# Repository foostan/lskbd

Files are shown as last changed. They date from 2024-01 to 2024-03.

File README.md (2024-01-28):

# lskbd

lskbd-low-layout v1 top
lskbd-low-layout v1 front
lskbd-low-layout v1 back

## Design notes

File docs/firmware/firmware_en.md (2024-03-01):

# Firmware

## Flash the firmware
Download the firmware of VIA from below
- [lskbd_rev1_via.uf2](https://github.com/foostan/kbd_firmware/blob/main/keyboards/lskbd/qmk/qmk_firmware/.build/lskbd_rev1_via.uf2)

Connect to the PC while holding down the BOOT button, or while connected to the PC, hold down the BOOT button and press the RESET button.
After that, an RPI-PR2 device will be mounted.

btn

Drop the downloaded uf2 file into the RPI-PR2 device to complete flash.

flash

Once the firmware has been written to one side, follow the same procedure for the other side.

## (Optional) If you build the firmware yourself

Refer to [the QMK _getting started_ guide](https://docs.qmk.fm/#/newbs_getting_started),
and install the necessary software according to your OS
(it takes quite some time to install).

Once the environment is ready,
build the firmware for LSKBD with the following files.
https://github.com/foostan/kbd_firmware/tree/main/keyboards/lskbd/qmk/qmk_firmware

## Change your keymap

Please download json file from bellow and load at VIA
- [lskbd](https://github.com/foostan/kbd_firmware/blob/main/keyboards/lskbd/the-via/lskbd.json)

load_json
loaded_json

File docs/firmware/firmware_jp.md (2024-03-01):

# ファームウェア

## ファームウェアを書き込む

VIA用のファームウェアを下記からダウンロードします
- [lskbd_rev1_via.uf2](https://github.com/foostan/kbd_firmware/blob/main/keyboards/lskbd/qmk/qmk_firmware/.build/lskbd_rev1_via.uf2)

BOOTボタンを押しながらPCに接続するか、PCに接続した状態でBOOTボタンを押しながらリセットボタンを押します。
すると、RPI-PR2デバイスがマウントされます。

btn

ダウンロードしたuf2ファイルをRPI-PR2デバイスにドロップすると書き込みが完了します。

flash

片側にファームウェアの書き込みが完了したら、もう片方も同じ手順で書き込みを行います。

## (オプション) 自分でファームウェアをビルドする場合

[the QMK _getting started_ guide](https://docs.qmk.fm/#/newbs_getting_started) こちらを参照して頂き、ファームウェアを書き込む環境を用意します。

環境ができましたら、下記のファイルを利用して自身でビルドを行ってください。
https://github.com/foostan/kbd_firmware/tree/main/keyboards/crkbd/qmk/qmk_firmware

## Change your keymap

下記からjsonファイルをダウンロードし、VIAでロードしてください。
- [lskbd](https://github.com/foostan/kbd_firmware/blob/main/keyboards/lskbd/the-via/lskbd.json)

load_json
loaded_json

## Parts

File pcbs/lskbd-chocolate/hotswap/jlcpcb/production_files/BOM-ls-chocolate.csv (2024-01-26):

Comment | Designator | Footprint | LCSC
W25Q128JVSIQ | U3,rU3 | SOIC-8_5.23x5.23mm_P1.27mm | C113767
1k | R4,R7,rR4,rR7 | R_0402_1005Metric | C11702
TPD4E05U06DQAR | U2,rU2 | USON-10_2.5x1.0mm_P0.5mm | C138714
NCP1117LPST33T3G | U1,rU1 | SOT-223-3_TabPin2 | C146799
100n | C10,C11,C12,C4,C5,C6,C7,C8,C9,rC10,rC11,rC12,rC4,rC5,rC6,rC7,rC8,rC9 | C_0402_1005Metric | C1525
10u | C1,C2,rC1,rC2 | C_0402_1005Metric | C15525
27p | C15,C16,rC15,rC16 | C_0402_1005Metric | C1557
RP2040 | U4,rU4 | QFN-56-1EP_7x7mm_P0.4mm_EP3.2x3.2mm | C2040
1N4148WT | D1,rD1 | D_SOD-523 | C232841
10k | R3,rR3 | R_0402_1005Metric | C25744
5.1k | R1,R2,rR1,rR2 | R_0402_1005Metric | C25905
ST-0277D00-052-142 | J1,rJ1 | ST-0277D00-052-142 | C2837093
BSMD0603-050-12V | F1,rF1 | Fuse_0603_1608Metric | C2844464
TYPE-C-31-M-13C | J3,rJ3 | TYPE-C-31-M-13C | C2848620
ESD5Z5V0C | ZD1,rZD1 | D_SOD-523 | C2901325
27 | R5,R6,rR5,rR6 | R_0402_1005Metric | C2909343
TS-1088R-02026 | SMDSW1,SMDSW2,rSMDSW1,rSMDSW2 | TS-1088R-02026 | C455280
YS-SK6812MINI-E | LED1,LED10,LED11,LED12,LED13,LED14,LED15,LED16,LED17,LED18,LED19,LED2,LED20,LED21,LED22,LED23,LED24,LED3,LED4,LED5,LED6,LED7,LED8,LED9,rLED1,rLED10,rLED11,rLED12,rLED13,rLED14,rLED15,rLED16,rLED17,rLED18,rLED19,rLED2,rLED20,rLED21,rLED22,rLED23,rLED24,rLED3,rLED4,rLED5,rLED6,rLED7,rLED8,rLED9 | YS-SK6812MINI-E | C5149201
1u | C13,C14,C3,rC13,rC14,rC3 | C_0402_1005Metric | C52923
SW_Push | SW1,SW10,SW11,SW12,SW13,SW14,SW15,SW16,SW17,SW18,SW19,SW2,SW20,SW21,SW22,SW23,SW24,SW3,SW4,SW5,SW6,SW7,SW8,SW9,rSW1,rSW10,rSW11,rSW12,rSW13,rSW14,rSW15,rSW16,rSW17,rSW18,rSW19,rSW2,rSW20,rSW21,rSW22,rSW23,rSW24,rSW3,rSW4,rSW5,rSW6,rSW7,rSW8,rSW9 | keyswitch_choc12_hotswap_1u | C5333465
12MHz 18pF | Y1,rY1 | Crystal_SMD_3225-4Pin_3.2x2.5mm | C91749

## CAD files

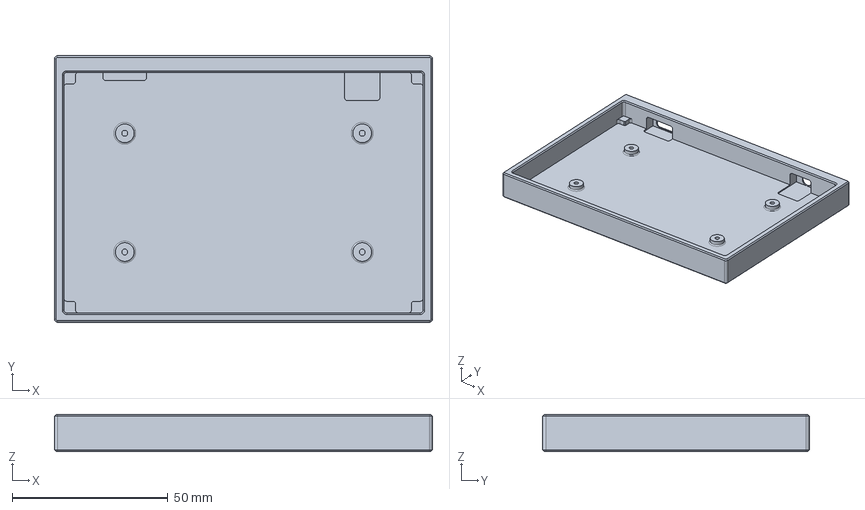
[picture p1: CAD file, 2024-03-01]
cases/lskbd-chocolate/lskbd-chocolate-left.step
121.3 x 85.5 x 11.9 mm

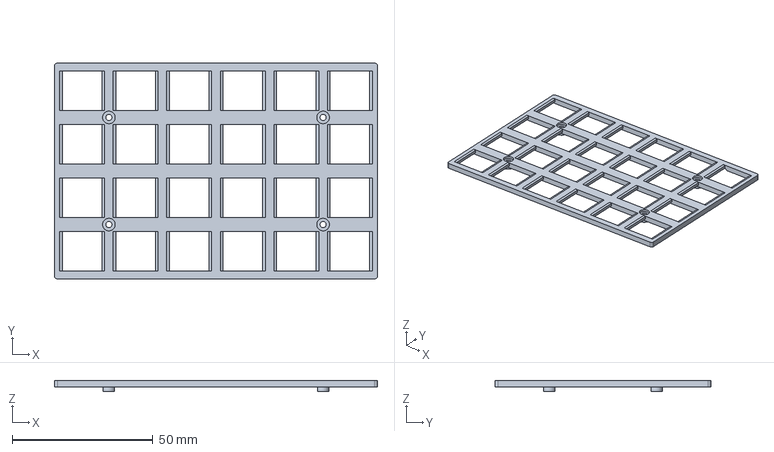
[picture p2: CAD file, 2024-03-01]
cases/lskbd-chocolate/lskbd-chocolate-plate-left.step
114.9 x 76.8 x 4.00 mm

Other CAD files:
cases/lskbd-chocolate/lskbd-chocolate-right.step
cases/lskbd-chocolate/lskbd-chocolate-plate-right.step

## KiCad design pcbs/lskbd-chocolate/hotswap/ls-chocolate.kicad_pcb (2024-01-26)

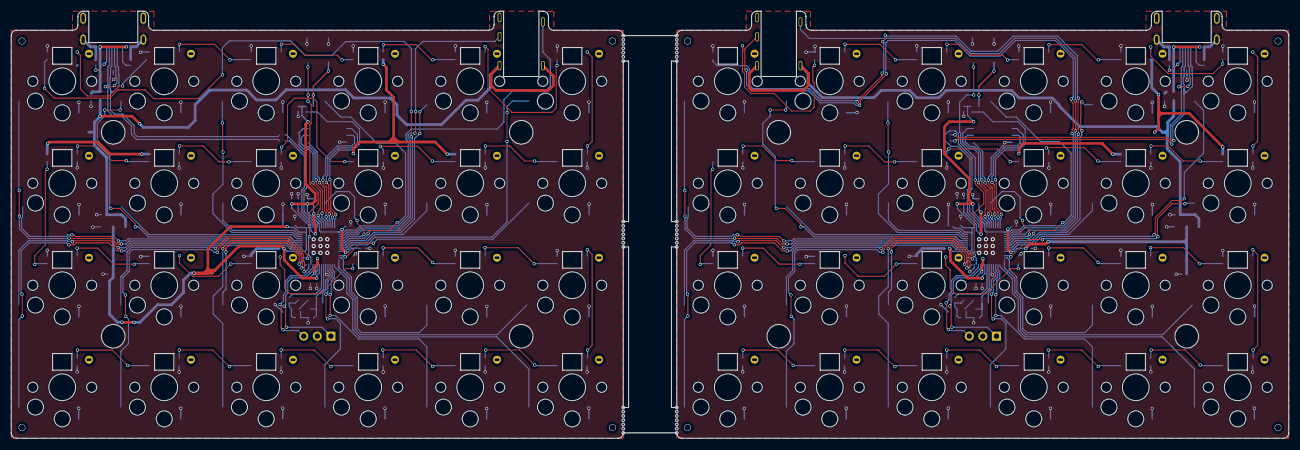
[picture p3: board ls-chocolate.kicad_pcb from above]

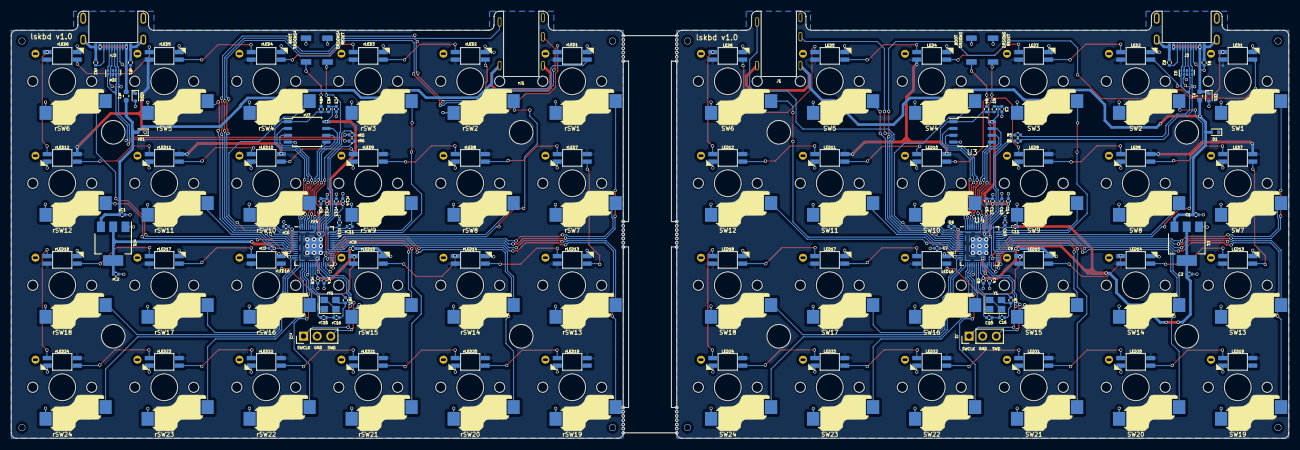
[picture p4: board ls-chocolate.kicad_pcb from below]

Board: 2 copper layers, 238.6 x 79.8 mm, 174 parts (168 on the bottom side), 150 nets.

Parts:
BT1, BT2, BT3: Breakaway Tabs; Breakaway_Tabs
C1, C2: 10u; C_0402_1005Metric
C3, C13, C14: 1u; C_0402_1005Metric
C4, C5, C6, C7, C8, C9, C10, C11, C12: 100n; C_0402_1005Metric
C15, C16: 27p; C_0402_1005Metric
D1: 1N4148WT; D_SOD-523
F1: BSMD0603-050-12V; Fuse_0603_1608Metric
J1: ST-0277D00-052-142
J2: Conn_01x03; PinHeader_1x03_P2.54mm_Vertical
J3: TYPE-C-31-M-13C
LED1, LED2, LED3, LED4, LED5, LED6, LED7, LED8, LED9, LED10, LED11, LED12, LED13, LED14, LED15, LED16, LED17, LED18, LED19, LED20, LED21, LED22, LED23, LED24: YS-SK6812MINI-E
R1, R2: 5.1k; R_0402_1005Metric
R3: 10k; R_0402_1005Metric
R4, R7: 1k; R_0402_1005Metric
R5, R6: 27; R_0402_1005Metric
SMDSW1, SMDSW2: TS-1088R-02026
SW1, SW2, SW3, SW4, SW5, SW6, SW7, SW8, SW9, SW10, SW11, SW12, SW13, SW14, SW15, SW16, SW17, SW18, SW19, SW20, SW21, SW22, SW23, SW24: SW_Push; keyswitch_choc12_hotswap_1u
U1: NCP1117LPST33T3G; SOT-223-3_TabPin2
U2: TPD4E05U06DQAR; USON-10_2.5x1.0mm_P0.5mm
U3: W25Q128JVSIQ; SOIC-8_5.23x5.23mm_P1.27mm
U4: RP2040; QFN-56-1EP_7x7mm_P0.4mm_EP3.2x3.2mm
Y1: 12MHz 18pF; Crystal_SMD_3225-4Pin_3.2x2.5mm
ZD1: ESD5Z5V0C; D_SOD-523
rBT1, rBT2, rBT3: Breakaway Tabs; Breakaway_Tabs
rC1, rC2: 10u; C_0402_1005Metric
rC3, rC13, rC14: 1u; C_0402_1005Metric
rC4, rC5, rC6, rC7, rC8, rC9, rC10, rC11, rC12: 100n; C_0402_1005Metric
rC15, rC16: 27p; C_0402_1005Metric
rD1: 1N4148WT; D_SOD-523
rF1: BSMD0603-050-12V; Fuse_0603_1608Metric
rJ1: ST-0277D00-052-142
rJ2: Conn_01x03; PinHeader_1x03_P2.54mm_Vertical
rJ3: TYPE-C-31-M-13C
rLED1, rLED2, rLED3, rLED4, rLED5, rLED6, rLED7, rLED8, rLED9, rLED10, rLED11, rLED12, rLED13, rLED14, rLED15, rLED16, rLED17, rLED18, rLED19, rLED20, rLED21, rLED22, rLED23, rLED24: YS-SK6812MINI-E
rR1, rR2: 5.1k; R_0402_1005Metric
rR3: 10k; R_0402_1005Metric
rR4, rR7: 1k; R_0402_1005Metric
rR5, rR6: 27; R_0402_1005Metric
rSMDSW1, rSMDSW2: TS-1088R-02026
rSW1, rSW2, rSW3, rSW4, rSW5, rSW6, rSW7, rSW8, rSW9, rSW10, rSW11, rSW12, rSW13, rSW14, rSW15, rSW16, rSW17, rSW18, rSW19, rSW20, rSW21, rSW22, rSW23, rSW24: SW_Push; keyswitch_choc12_hotswap_1u
rU1: NCP1117LPST33T3G; SOT-223-3_TabPin2
rU2: TPD4E05U06DQAR; USON-10_2.5x1.0mm_P0.5mm
rU3: W25Q128JVSIQ; SOIC-8_5.23x5.23mm_P1.27mm
rU4: RP2040; QFN-56-1EP_7x7mm_P0.4mm_EP3.2x3.2mm
rY1: 12MHz 18pF; Crystal_SMD_3225-4Pin_3.2x2.5mm
rZD1: ESD5Z5V0C; D_SOD-523

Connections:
+1V1: C4.1, C5.1, C13.1, U4.23 (DVDD), U4.45 (VREG_VOUT), U4.50 (DVDD)
+1V1R: rC4.1, rC5.1, rC13.1, rU4.23 (DVDD), rU4.45 (VREG_VOUT), rU4.50 (DVDD)
+3V3: C2.1, C3.1, C6.1, C7.1, C8.1, C9.1, C10.1, C11.1, C12.1, C14.1, R3.2, U1.2 (VO), U3.8 (VCC), U4.1 (IOVDD), U4.10 (IOVDD), U4.22 (IOVDD), U4.32 (GPIO21), U4.33 (IOVDD), U4.42 (IOVDD), U4.43 (ADC_AVDD), U4.44 (VREG_IN), U4.48 (USB_VDD), U4.49 (IOVDD)
+3V3R: rC2.1, rC3.1, rC6.1, rC7.1, rC8.1, rC9.1, rC10.1, rC11.1, rC12.1, rC14.1, rR3.2, rU1.2 (VO), rU3.8 (VCC), rU4.1 (IOVDD), rU4.10 (IOVDD), rU4.22 (IOVDD), rU4.33 (IOVDD), rU4.42 (IOVDD), rU4.43 (ADC_AVDD), rU4.44 (VREG_IN), rU4.48 (USB_VDD), rU4.49 (IOVDD)
+5V: C1.1, D1.2 (A), F1.2, J1.T, U1.3 (VI)
+5VR: rC1.1, rD1.2 (A), rF1.2, rJ1.T, rU1.3 (VI)
/left/D+: J3.A6 (D+), J3.B6 (D+), R5.1, U2.1 (D1+), U2.4 (D2+), U2.7 (NC), U2.10 (NC)
/left/D-: J3.A7 (D-), J3.B7 (D-), R6.2, U2.2 (D1-), U2.5 (D2-), U2.6 (NC), U2.9 (NC)
/left/KEY1: SW1.1, U4.36 (GPIO24)
/left/KEY2: SW2.1, U4.38 (GPIO26_ADC0)
/left/KEY3: SW3.1, U4.40 (GPIO28_ADC2)
/left/KEY4: SW4.1, U4.6 (GPIO4)
/left/KEY5: SW5.1, U4.7 (GPIO5)
/left/KEY6: SW6.1, U4.9 (GPIO7)
/left/KEY7: SW7.1, U4.37 (GPIO25)
/left/KEY8: SW8.1, U4.39 (GPIO27_ADC1)
/left/KEY9: SW9.1, U4.41 (GPIO29_ADC3)
/left/KEY10: SW10.1, U4.5 (GPIO3)
/left/KEY11: SW11.1, U4.8 (GPIO6)
/left/KEY12: SW12.1, U4.12 (GPIO9)
/left/KEY13: SW13.1, U4.35 (GPIO23)
/left/KEY14: SW14.1, U4.30 (GPIO19)
/left/KEY15: SW15.1, U4.29 (GPIO18)
/left/KEY16: SW16.1, U4.18 (GPIO15)
/left/KEY17: SW17.1, U4.13 (GPIO10)
/left/KEY18: SW18.1, U4.14 (GPIO11)
/left/KEY19: SW19.1, U4.34 (GPIO22)
/left/KEY20: SW20.1, U4.27 (GPIO16)
/left/KEY21: SW21.1, U4.28 (GPIO17)
/left/KEY22: SW22.1, U4.17 (GPIO14)
/left/KEY23: SW23.1, U4.16 (GPIO13)
/left/KEY24: SW24.1, U4.15 (GPIO12)
/left/LED: LED1.4 (DIN), U4.4 (GPIO2)
/left/QSPI_SCLK: U3.6 (CLK), U4.52 (QSPI_SCLK)
/left/QSPI_SD0: U3.5 (DI(IO0)), U4.53 (QSPI_SD0)
/left/QSPI_SD1: U3.2 (DO(IO1)), U4.55 (QSPI_SD1)
/left/QSPI_SD2: U3.3 (IO2), U4.54 (QSPI_SD2)
/left/QSPI_SD3: U3.7 (IO3), U4.51 (QSPI_SD3)
/left/QSPI_SS: R3.1, R4.1, U3.1 (~CS), U4.56 (QSPI_SS)
/left/RX: J1.R1, U4.3 (GPIO1)
/left/SWCLK: J2.1, U4.24 (SWCLK)
/left/SWD: J2.3, U4.25 (SWD)
/left/TX: J1.R2, U4.2 (GPIO0)
/right/D+: rJ3.A6 (D+), rJ3.B6 (D+), rR5.1, rU2.1 (D1+), rU2.4 (D2+), rU2.7 (NC), rU2.10 (NC)
/right/D-: rJ3.A7 (D-), rJ3.B7 (D-), rR6.2, rU2.2 (D1-), rU2.5 (D2-), rU2.6 (NC), rU2.9 (NC)
/right/KEY1: rSW1.1, rU4.36 (GPIO24)
/right/KEY2: rSW2.1, rU4.38 (GPIO26_ADC0)
/right/KEY3: rSW3.1, rU4.40 (GPIO28_ADC2)
/right/KEY4: rSW4.1, rU4.6 (GPIO4)
/right/KEY5: rSW5.1, rU4.7 (GPIO5)
/right/KEY6: rSW6.1, rU4.9 (GPIO7)
/right/KEY7: rSW7.1, rU4.37 (GPIO25)
/right/KEY8: rSW8.1, rU4.39 (GPIO27_ADC1)
/right/KEY9: rSW9.1, rU4.41 (GPIO29_ADC3)
/right/KEY10: rSW10.1, rU4.5 (GPIO3)
/right/KEY11: rSW11.1, rU4.8 (GPIO6)
/right/KEY12: rSW12.1, rU4.12 (GPIO9)
/right/KEY13: rSW13.1, rU4.35 (GPIO23)
/right/KEY14: rSW14.1, rU4.30 (GPIO19)
/right/KEY15: rSW15.1, rU4.29 (GPIO18)
/right/KEY16: rSW16.1, rU4.18 (GPIO15)
/right/KEY17: rSW17.1, rU4.13 (GPIO10)
/right/KEY18: rSW18.1, rU4.14 (GPIO11)
/right/KEY19: rSW19.1, rU4.34 (GPIO22)
/right/KEY20: rSW20.1, rU4.27 (GPIO16)
/right/KEY21: rSW21.1, rU4.28 (GPIO17)
/right/KEY22: rSW22.1, rU4.17 (GPIO14)
/right/KEY23: rSW23.1, rU4.16 (GPIO13)
/right/KEY24: rSW24.1, rU4.15 (GPIO12)
/right/LED: rLED1.4 (DIN), rU4.4 (GPIO2)
/right/QSPI_SCLK: rU3.6 (CLK), rU4.52 (QSPI_SCLK)
/right/QSPI_SD0: rU3.5 (DI(IO0)), rU4.53 (QSPI_SD0)
/right/QSPI_SD1: rU3.2 (DO(IO1)), rU4.55 (QSPI_SD1)
/right/QSPI_SD2: rU3.3 (IO2), rU4.54 (QSPI_SD2)
/right/QSPI_SD3: rU3.7 (IO3), rU4.51 (QSPI_SD3)
/right/QSPI_SS: rR3.1, rR4.1, rU3.1 (~CS), rU4.56 (QSPI_SS)
/right/RX: rJ1.R2, rU4.3 (GPIO1)
/right/SWCLK: rJ2.1, rU4.24 (SWCLK)
/right/SWD: rJ2.3, rU4.25 (SWD)
/right/TX: rJ1.R1, rU4.2 (GPIO0)
GND: C1.2, C2.2, C3.2, C4.2, C5.2, C6.2, C7.2, C8.2, C9.2, C10.2, C11.2, C12.2, C13.2, C14.2, C15.2, C16.2, J1.S, J2.2, J3.A1 (GND), J3.A12 (GND), J3.B1 (GND), J3.B12 (GND), J3.S1 (SHIELD), LED1.3 (VSS), LED2.3 (VSS), LED3.3 (VSS), LED4.3 (VSS), LED5.3 (VSS), LED6.3 (VSS), LED7.3 (VSS), LED8.3 (VSS), LED9.3 (VSS), LED10.3 (VSS), LED11.3 (VSS), LED12.3 (VSS), LED13.3 (VSS), LED14.3 (VSS), LED15.3 (VSS), LED16.3 (VSS), LED17.3 (VSS), LED18.3 (VSS), LED19.3 (VSS), LED20.3 (VSS), LED21.3 (VSS), LED22.3 (VSS), LED23.3 (VSS), LED24.3 (VSS), R1.1, R2.1, SMDSW1.1, SMDSW2.1, SW1.2, SW2.2, SW3.2, SW4.2, SW5.2, SW6.2, SW7.2, SW8.2, SW9.2, SW10.2, SW11.2, SW12.2, SW13.2, SW14.2, SW15.2, SW16.2, SW17.2, SW18.2, SW19.2, SW20.2, SW21.2, SW22.2, SW23.2, SW24.2, U1.1 (GND), U2.3 (GND), U2.8 (GND), U3.4 (GND), U4.19 (TESTEN), U4.57 (GND), Y1.2, Y1.4, ZD1.2 (A)
GNDR: rC1.2, rC2.2, rC3.2, rC4.2, rC5.2, rC6.2, rC7.2, rC8.2, rC9.2, rC10.2, rC11.2, rC12.2, rC13.2, rC14.2, rC15.2, rC16.2, rJ1.S, rJ2.2, rJ3.A1 (GND), rJ3.A12 (GND), rJ3.B1 (GND), rJ3.B12 (GND), rJ3.S1 (SHIELD), rLED1.3 (VSS), rLED2.3 (VSS), rLED3.3 (VSS), rLED4.3 (VSS), rLED5.3 (VSS), rLED6.3 (VSS), rLED7.3 (VSS), rLED8.3 (VSS), rLED9.3 (VSS), rLED10.3 (VSS), rLED11.3 (VSS), rLED12.3 (VSS), rLED13.3 (VSS), rLED14.3 (VSS), rLED15.3 (VSS), rLED16.3 (VSS), rLED17.3 (VSS), rLED18.3 (VSS), rLED19.3 (VSS), rLED20.3 (VSS), rLED21.3 (VSS), rLED22.3 (VSS), rLED23.3 (VSS), rLED24.3 (VSS), rR1.1, rR2.1, rSMDSW1.1, rSMDSW2.1, rSW1.2, rSW2.2, rSW3.2, rSW4.2, rSW5.2, rSW6.2, rSW7.2, rSW8.2, rSW9.2, rSW10.2, rSW11.2, rSW12.2, rSW13.2, rSW14.2, rSW15.2, rSW16.2, rSW17.2, rSW18.2, rSW19.2, rSW20.2, rSW21.2, rSW22.2, rSW23.2, rSW24.2, rU1.1 (GND), rU2.3 (GND), rU2.8 (GND), rU3.4 (GND), rU4.19 (TESTEN), rU4.32 (GPIO21), rU4.57 (GND), rY1.2, rY1.4, rZD1.2 (A)
unnamed: C16.1, R7.1, Y1.3
unnamed: D1.1 (K), LED1.1 (VDD), LED2.1 (VDD), LED3.1 (VDD), LED4.1 (VDD), LED5.1 (VDD), LED6.1 (VDD), LED7.1 (VDD), LED8.1 (VDD), LED9.1 (VDD), LED10.1 (VDD), LED11.1 (VDD), LED12.1 (VDD), LED13.1 (VDD), LED14.1 (VDD), LED15.1 (VDD), LED16.1 (VDD), LED17.1 (VDD), LED18.1 (VDD), LED19.1 (VDD), LED20.1 (VDD), LED21.1 (VDD), LED22.1 (VDD), LED23.1 (VDD), LED24.1 (VDD)
unnamed: J3.A5 (CC1), R1.2
unnamed: J3.B5 (CC2), R2.2
unnamed: LED1.2 (DOUT), LED2.4 (DIN)
unnamed: LED2.2 (DOUT), LED3.4 (DIN)
unnamed: LED3.2 (DOUT), LED4.4 (DIN)
unnamed: LED4.2 (DOUT), LED5.4 (DIN)
unnamed: LED5.2 (DOUT), LED6.4 (DIN)
unnamed: LED7.4 (DIN), LED8.2 (DOUT)
unnamed: LED8.4 (DIN), LED9.2 (DOUT)
unnamed: LED10.4 (DIN), LED11.2 (DOUT)
unnamed: LED9.4 (DIN), LED10.2 (DOUT)
unnamed: LED11.4 (DIN), LED12.2 (DOUT)
unnamed: LED6.2 (DOUT), LED12.4 (DIN)
unnamed: LED7.2 (DOUT), LED13.4 (DIN)
unnamed: LED13.2 (DOUT), LED14.4 (DIN)
unnamed: LED14.2 (DOUT), LED15.4 (DIN)
unnamed: LED15.2 (DOUT), LED16.4 (DIN)
unnamed: LED16.2 (DOUT), LED17.4 (DIN)
unnamed: LED17.2 (DOUT), LED18.4 (DIN)
unnamed: LED18.2 (DOUT), LED24.4 (DIN)
unnamed: LED19.4 (DIN), LED20.2 (DOUT)
unnamed: LED20.4 (DIN), LED21.2 (DOUT)
unnamed: LED21.4 (DIN), LED22.2 (DOUT)
unnamed: LED22.4 (DIN), LED23.2 (DOUT)
unnamed: LED23.4 (DIN), LED24.2 (DOUT)
unnamed: R4.2, SMDSW1.2
unnamed: SMDSW2.2, U4.26 (RUN)
unnamed: R6.1, U4.46 (USB_DM)
unnamed: R5.2, U4.47 (USB_DP)
unnamed: C15.1, U4.20 (XIN), Y1.1
unnamed: R7.2, U4.21 (XOUT)
unnamed: rC16.1, rR7.1, rY1.3
unnamed: rD1.1 (K), rLED1.1 (VDD), rLED2.1 (VDD), rLED3.1 (VDD), rLED4.1 (VDD), rLED5.1 (VDD), rLED6.1 (VDD), rLED7.1 (VDD), rLED8.1 (VDD), rLED9.1 (VDD), rLED10.1 (VDD), rLED11.1 (VDD), rLED12.1 (VDD), rLED13.1 (VDD), rLED14.1 (VDD), rLED15.1 (VDD), rLED16.1 (VDD), rLED17.1 (VDD), rLED18.1 (VDD), rLED19.1 (VDD), rLED20.1 (VDD), rLED21.1 (VDD), rLED22.1 (VDD), rLED23.1 (VDD), rLED24.1 (VDD)
unnamed: rJ3.A5 (CC1), rR1.2
unnamed: rJ3.B5 (CC2), rR2.2
unnamed: rLED1.2 (DOUT), rLED2.4 (DIN)
unnamed: rLED2.2 (DOUT), rLED3.4 (DIN)
unnamed: rLED3.2 (DOUT), rLED4.4 (DIN)
unnamed: rLED4.2 (DOUT), rLED5.4 (DIN)
unnamed: rLED5.2 (DOUT), rLED6.4 (DIN)
unnamed: rLED7.4 (DIN), rLED8.2 (DOUT)
unnamed: rLED8.4 (DIN), rLED9.2 (DOUT)
unnamed: rLED10.4 (DIN), rLED11.2 (DOUT)
unnamed: rLED9.4 (DIN), rLED10.2 (DOUT)
unnamed: rLED11.4 (DIN), rLED12.2 (DOUT)
unnamed: rLED6.2 (DOUT), rLED12.4 (DIN)
unnamed: rLED7.2 (DOUT), rLED13.4 (DIN)
unnamed: rLED13.2 (DOUT), rLED14.4 (DIN)
unnamed: rLED14.2 (DOUT), rLED15.4 (DIN)
unnamed: rLED15.2 (DOUT), rLED16.4 (DIN)
unnamed: rLED16.2 (DOUT), rLED17.4 (DIN)
unnamed: rLED17.2 (DOUT), rLED18.4 (DIN)
unnamed: rLED18.2 (DOUT), rLED24.4 (DIN)
unnamed: rLED19.4 (DIN), rLED20.2 (DOUT)
unnamed: rLED20.4 (DIN), rLED21.2 (DOUT)
unnamed: rLED21.4 (DIN), rLED22.2 (DOUT)
unnamed: rLED22.4 (DIN), rLED23.2 (DOUT)
unnamed: rLED23.4 (DIN), rLED24.2 (DOUT)
unnamed: rR4.2, rSMDSW1.2
unnamed: rSMDSW2.2, rU4.26 (RUN)
unnamed: rR6.1, rU4.46 (USB_DM)
unnamed: rR5.2, rU4.47 (USB_DP)
unnamed: rC15.1, rU4.20 (XIN), rY1.1
unnamed: rR7.2, rU4.21 (XOUT)
VBUS: F1.1, J3.A4 (VBUS), J3.A9 (VBUS), J3.B4 (VBUS), J3.B9 (VBUS), ZD1.1 (K)
VBUSR: rF1.1, rJ3.A4 (VBUS), rJ3.A9 (VBUS), rJ3.B4 (VBUS), rJ3.B9 (VBUS), rZD1.1 (K)

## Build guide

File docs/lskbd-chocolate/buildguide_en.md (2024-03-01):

# Build Guide
This is the build guide for LSKBD.

lskbd-low-layout v1 front

## Parts

### Required

| Name | Count | Remarks |
|:---|:---|:---|
| PCB | 1 set | |
| Case | 1 set | |
| Switch plate | 1 set | |
| Key switches | 48 | Only Kailh choc v1 and v2 switches |
| Keycaps | 48 | 1u 48 pcs |
| Screw M2 | 8 | 5 mm |
| Rubber cushion | 8 | |
| TRRS (4 poles) cable | 1 | TRS (3 poles) cable is not compatible |
| Type-C cable | 1 | |

## Firmware preparation
If you build the firmware yourself, it will take some time to set up the environment,
so it's best to start at the beginning.\
For more information,
please see [docs/firmware](../firmware/firmware_en.md).

## Build
This is the build guide for the left hand side. The right side is the same procedure.

### 1: Attach switches to PCB
switches

### 2: Attach to case
case

### 3: Attach rubber cushions
rubber-cushion

### 4: Attach keycaps
keycap

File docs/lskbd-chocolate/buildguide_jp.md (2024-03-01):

# Build Guide
こちらは LSKBD Chocolate のビルドガイドになります。

lskbd-low-layout v1 front

## Parts

### Required

| Name | Count | Remarks |
|:---|:---|:---|
| PCB | 1 set | |
| Case | 1 set | |
| Switch plate | 1 set | |
| Key switches | 48 | Kailh choc v1 and v2 スイッチのみ |
| Keycaps | 48 | 1u 48 pcs |
| Screw M2 | 8 | 長さ 5 mm |
| Rubber cushion | 8 | |
| TRRS (4 poles) cable | 1 | TRS (3 poles) は非対応 |
| Type-C cable | 1 | |

## Firmware preparation

ファームウェアを自分でビルドする場合は環境を整備するのに時間がかかるのではじめに取り掛かっておくことをおすすめします。\
詳しくは [docs/firmware](../firmware/firmware_jp.md) を参照してください。

## Build
これは左手側のビルドガイドですが、右手側も手順は同じです。

### 1: キースイッチを取り付ける
switches

### 2: ケースに取り付ける
case

### 3: ラバークッションを取り付ける
rubber-cushion

### 4: キーキャップを取り付ける
keycap

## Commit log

2018-04-10 Add plate data
    [lskbd.dwg]
2018-05-22 Add a bottom plate
    [lskbd.dwg]
2018-05-22 Output pdf and dxf
    [lskbd.dxf]
2024-01-26 Add pcb files
    [left.kicad_sch, ls-chocolate.kicad_pcb, ls-chocolate.kicad_sch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]
2024-01-26 Squashed 'pcbs/common/kbd/' content from commit 43da0ca
    git-subtree-dir: pcbs/common/kbd
    git-subtree-split: 43da0ca3d5e3e0a628e7d64e4fce58097fee60bb
2024-01-26 Squashed 'pcbs/common/kbd/' changes from 43da0ca..1203fd9
    1203fd9 Update choc silk
    git-subtree-split: 1203fd98feca15ec3eaaca5674fcea1d56e84fb0
    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
2024-01-26 Set factory files
    [BOM-ls-chocolate.csv, ls-chocolate.kicad_pcb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]
2024-01-28 Update case files
    [lskbd-chocolate-left.step, lskbd-chocolate-plate-left.step, lskbd-chocolate-plate-right.step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]
2024-01-28 Update pcb
    [CPL-ls-chocolate.csv]
2024-03-01 Add buildguide
    [left.kicad_sch, lskbd-chocolate-left.step, lskbd-chocolate-plate-left.step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]
2024-03-01 Update case data
    [lskbd-chocolate-left.step, lskbd-chocolate-plate-left.step, lskbd-chocolate-plate-right.step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]
